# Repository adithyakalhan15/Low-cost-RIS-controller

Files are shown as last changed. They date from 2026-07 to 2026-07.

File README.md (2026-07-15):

## Intelligent RIS Controller and User-Tracking System

This repository contains the hardware-control, embedded firmware, edge-processing, and desktop-visualization components developed for a low-cost Reconfigurable Intelligent Surface system operating near 2.4 GHz.

The system controls a 6 × 4, 1-bit RIS panel through a 24-channel shift-register and MOSFET driver architecture. An ESP32-S3 collects target information from dual LD2450 mmWave radar sensors, while RSSI measurements provide additional wireless-positioning information. A Raspberry Pi processes the sensor data, selects RIS control patterns, and communicates with a Python-based desktop application for visualization, manual control, logging, and system monitoring.

The project demonstrates the integration of RF hardware, embedded systems, wireless sensing, edge processing, and software interfaces in a single experimental RIS platform.

### Main Features

* Independent control of 24 RIS cells
* ESP32-S3-based dual-radar data acquisition
* Radar and RSSI-assisted user tracking
* Raspberry Pi edge server and GPIO control
* Manual and automatic RIS pattern selection
* Python desktop dashboard for monitoring and visualization
* RF experimentation using Vivaldi antennas, an NI USRP N210, and spectrum-analysis equipment

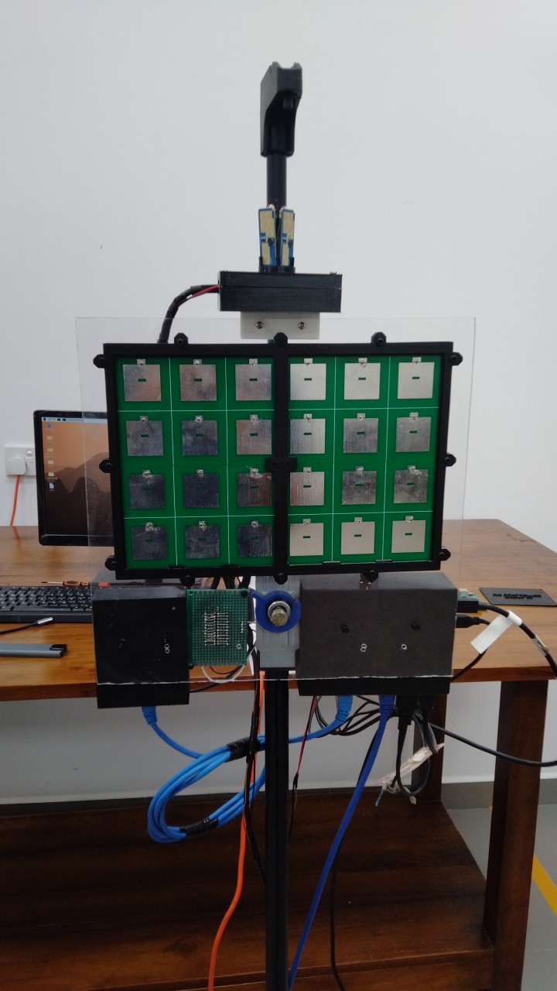
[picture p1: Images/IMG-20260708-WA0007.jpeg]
RIS setup with controller


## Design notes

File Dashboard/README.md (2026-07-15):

# RIS Master Modern Tabbed GUI — Performance Fixed

This version fixes UI freezing/messy rendering by throttling heavy Matplotlib redraws.

Key changes:
- Network packets are buffered; only the newest packet is rendered.
- Main UI refresh runs at 4 Hz.
- 2D plot redraws only when the Visual tab is active.
- 3D plot redraws slower, about 1 Hz, because 3D Matplotlib is expensive.
- Channel chart redraws only when the Channel tab is active.
- RIS panel remains 4 x 6 physical cells.
- Wire stream remains 32 bits: each 6-cell row + 2 dummy bits.

Run:

```bash
python -m venv .venv
```

Windows:

```powershell
.venv\Scripts\activate
pip install -r requirements.txt
python -m laptop_gui.main
```

Linux/Raspberry Pi OS/macOS:

```bash
source .venv/bin/activate
pip install -r requirements.txt
python -m laptop_gui.main
```

For Raspberry Pi connection:
- IP: your Pi Ethernet IP, for example 192.168.10.2
- Port: 5050
- Turn Simulation Mode OFF before connecting.

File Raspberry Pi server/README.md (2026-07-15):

# Raspberry Pi RIS Server — GPIO Scope Debug Final

This package is configured to **drive real Raspberry Pi GPIO pins by default** using a slow SPI-like bit-banged interface with the direct lgpio backend for a 74HC595 shift-register chain.

It also prints very clear hardware logs, including:

- whether GPIO output is enabled
- which physical pins and BCM GPIO numbers are used
- the exact 32-bit wire pattern
- the shifted bit order
- every DATA bit and CLOCK pulse during scope tests
- the final LATCH pulse confirmation
- direct lgpio backend, with no RPi.GPIO import

---

## Physical wiring

Wire by **physical pin number** on the Raspberry Pi header:

| Signal | Raspberry Pi physical pin | BCM GPIO used in Python | RJ45 pin | 74HC595 pin |
|---|---:|---:|---:|---:|
| DATA / MOSI-like | 19 | GPIO10 | 1 | 14 SER |
| CLOCK / SCLK-like | 23 | GPIO11 | 2 | 11 SRCLK |
| LATCH / RCLK-like | 24 | GPIO8 | 3 | 12 RCLK |
| GND | 6 or 9 | GND | 8 | 8 GND |

74HC595 fixed pins:

| 74HC595 pin | Connect to |
|---:|---|
| 16 VCC | 3.3 V recommended |
| 8 GND | Raspberry Pi GND |
| 13 OE | GND |
| 10 MR / SRCLR | VCC |

> Important: Raspberry Pi GPIO is 3.3 V logic. If your shift-register board is powered at 5 V, use a proper level shifter.

---

## What changed in this version

In `raspberry_pi_server/config.py`:

```python
ENABLE_HARDWARE_OUTPUT = True
GPIO_BIT_DELAY_S = 0.005
SCOPE_TEST_BIT_DELAY_S = 0.010
TELEMETRY_HZ = 1.0
HARDWARE_VERBOSE_PRINT = True
```

So the normal RIS server now writes to real GPIO pins by default. The scope test is even slower than the server output.

---

## Install on Raspberry Pi

Copy/extract this folder to the Raspberry Pi, then run:

```bash
cd ~/Desktop/raspberry_pi_ris_server_final_gpio_scope_debug
sudo apt update
sudo apt remove -y python3-rpi.gpio python3-rpi-lgpio
sudo apt install -y python3-venv python3-pip python3-lgpio
python3 -m venv .venv --system-site-packages
source .venv/bin/activate
python -m pip install --upgrade pip
pip install numpy onnxruntime pyserial
```

If serial permission fails:

```bash
sudo usermod -a -G dialout $USER
sudo reboot
```

Then activate again:

```bash
cd ~/Desktop/raspberry_pi_ris_server_final_gpio_scope_debug
source .venv/bin/activate
```

---

## GPIO library conflict fix

This version does **not** use `RPi.GPIO`. It imports `lgpio` directly.

Do not install both of these together for this package:

```bash
python3-rpi.gpio
python3-rpi-lgpio
```

Use only:

```bash
sudo apt install -y python3-lgpio
```

If GPIO claiming fails, try a different gpiochip:

```bash
ls /dev/gpiochip*
export RIS_GPIOCHIP=0
python3 scope_pin_test.py

# If needed, try:
export RIS_GPIOCHIP=4
python3 scope_pin_test.py
```

---

## Best oscilloscope test

Run this first before connecting the full RIS panel:

```bash
cd ~/Desktop/raspberry_pi_ris_server_final_gpio_scope_debug
source .venv/bin/activate
python3 scope_pin_test.py
```

Oscilloscope connections:

```text
Scope GND    -> Raspberry Pi physical pin 6 or 9
DATA probe   -> Raspberry Pi physical pin 19
CLOCK probe  -> Raspberry Pi physical pin 23
LATCH probe  -> Raspberry Pi physical pin 24
```

Expected:

```text
DATA  changes 0 V / 3.3 V according to the pattern
CLOCK gives 32 slow pulses per pattern
LATCH gives 1 pulse after each 32-bit transfer
```

The test prints every bit:

```text
[HW TX #1] bit 01/32 DATA=1 -> CLOCK pulse
[HW TX #1] bit 02/32 DATA=0 -> CLOCK pulse
...
[HW DONE #1] 32 clock pulses sent, latch pulsed, DATA left LOW.
```

To make it even slower, edit:

```bash
nano raspberry_pi_server/config.py
```

Change:

```python
SCOPE_TEST_BIT_DELAY_S = 0.020
```

---

## Shift-register hardware test

This also forces output ON and sends fixed patterns plus a walking-one test:

```bash
cd ~/Desktop/raspberry_pi_ris_server_final_gpio_scope_debug
source .venv/bin/activate
python3 test_shift_register.py
```

---

## Run final RIS server

```bash
cd ~/Desktop/raspberry_pi_ris_server_final_gpio_scope_debug
source .venv/bin/activate
python3 -m raspberry_pi_server.pi_server
```

Then connect the laptop GUI to the Raspberry Pi:

```text
IP: <your Raspberry Pi IP address>
Port: 5050
```

Useful command to find the Pi IP:

```bash
hostname -I
```

---

## If GPIO does not output

If you see this:

```text
[HW] RPi.GPIO import failed. Hardware output is disabled.
```

run:

```bash
sudo apt update
sudo apt install -y python3-rpi-lgpio python3-rpi.gpio
rm -rf .venv
python3 -m venv .venv --system-site-packages
source .venv/bin/activate
pip install numpy onnxruntime pyserial
python3 scope_pin_test.py
```

---

## Is this real SPI?

It is **SPI-like bit-banged GPIO**, not hardware `/dev/spidev` SPI.

That is intentional for debugging:

```text
DATA  = MOSI-like
CLOCK = SCLK-like
LATCH = CS/LOAD/RCLK-like
```

For the 74HC595 this is correct and easy to verify on the oscilloscope.

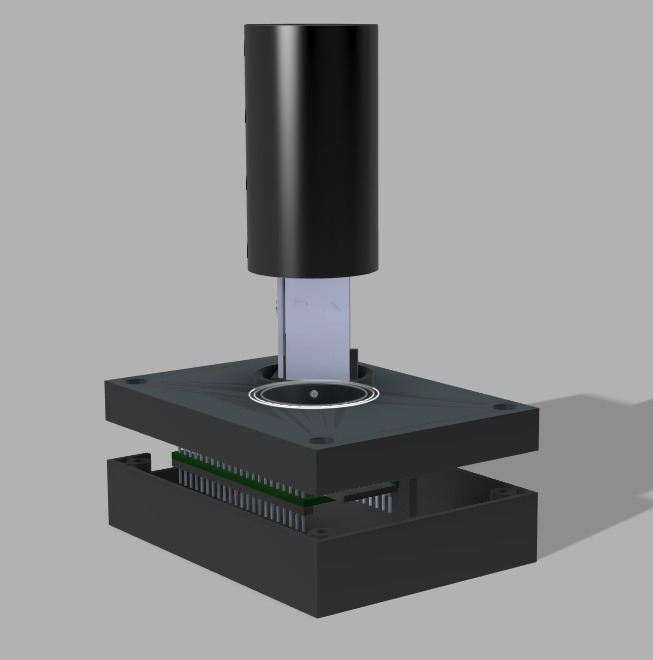
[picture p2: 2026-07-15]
Images/radar pod.jpeg

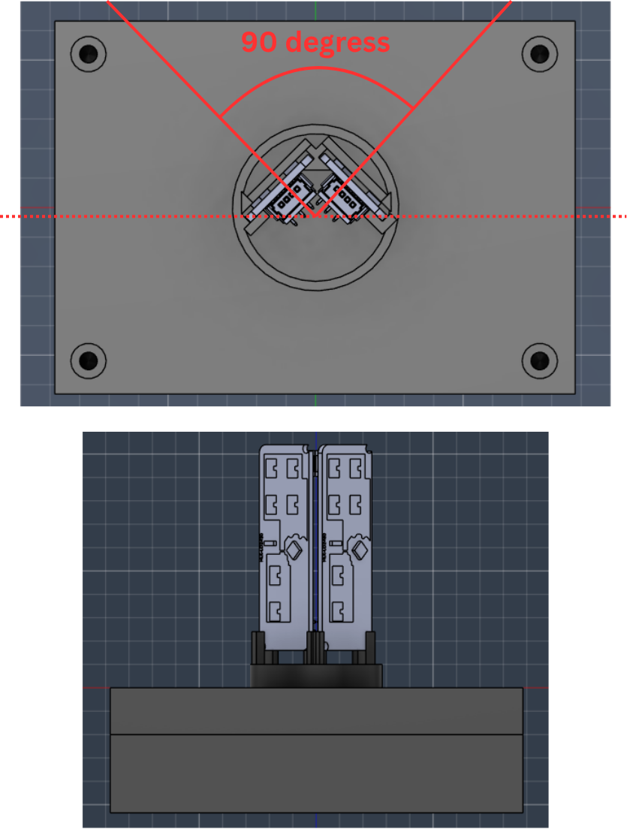
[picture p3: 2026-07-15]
Images/ON.png

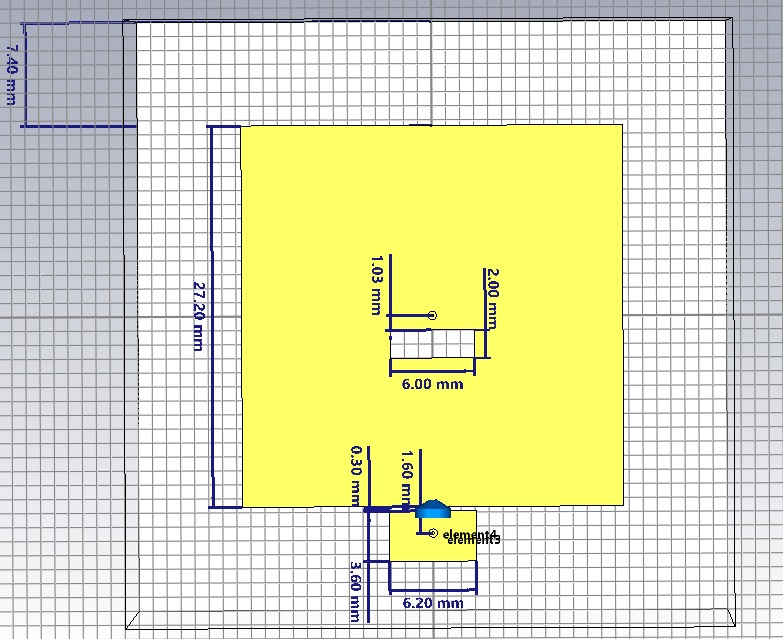
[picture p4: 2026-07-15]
Images/ris_unit_cell.jpeg

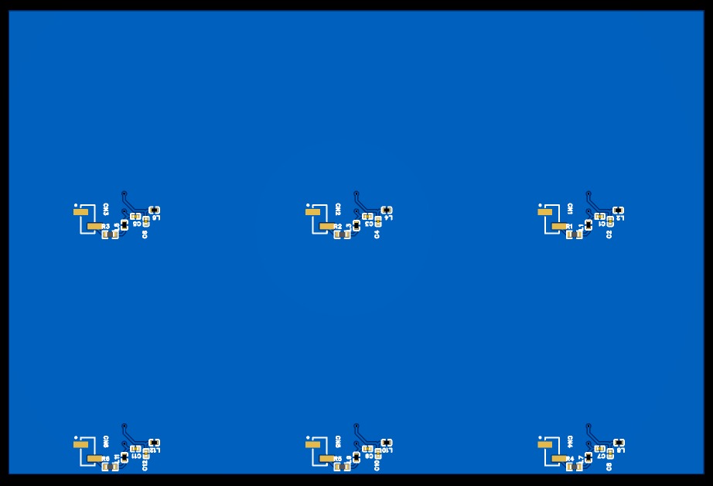
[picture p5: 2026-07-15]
Images/panel back.jpeg

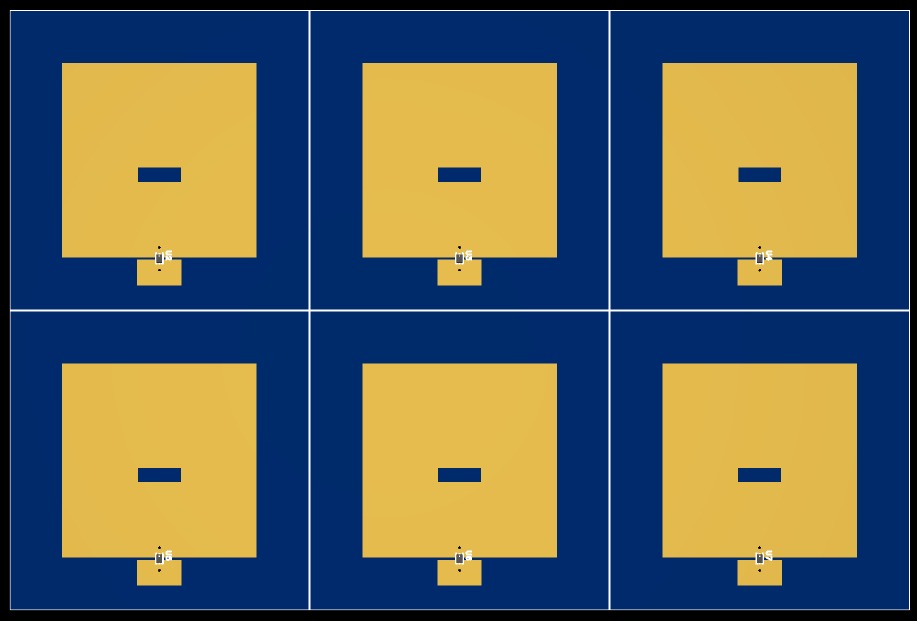
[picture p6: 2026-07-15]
Images/panel front.jpeg

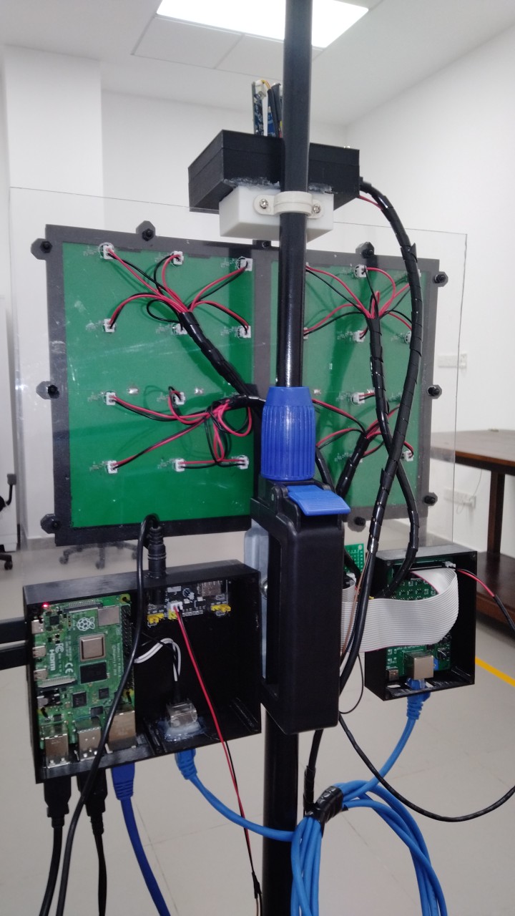
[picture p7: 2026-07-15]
Images/IMG-20260708-WA0011.jpeg

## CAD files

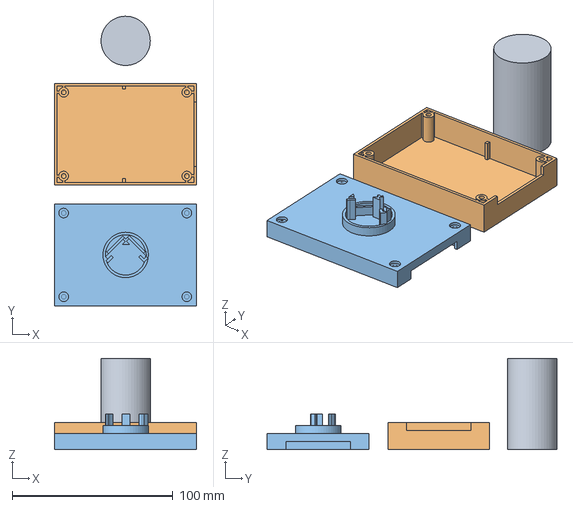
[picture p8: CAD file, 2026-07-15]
3D Files/Radar pod full.step
88.2 x 179.9 x 56.6 mm

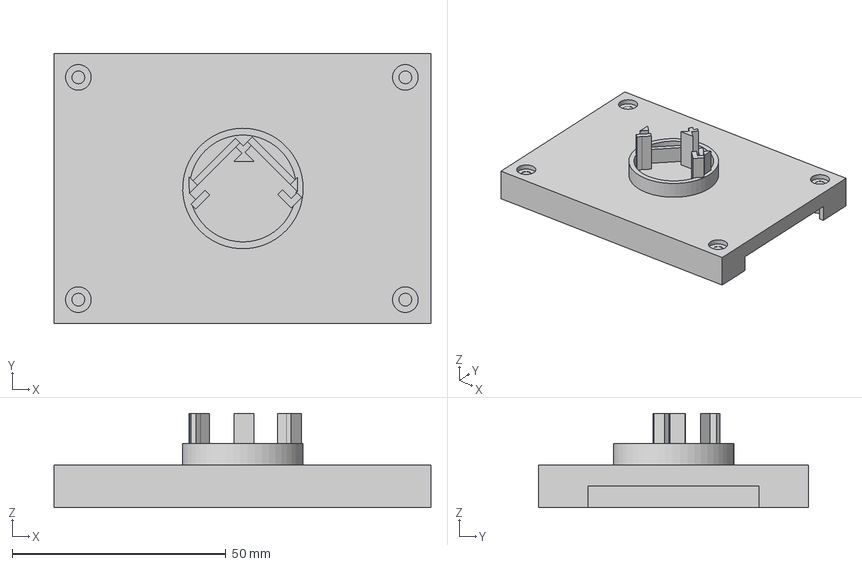
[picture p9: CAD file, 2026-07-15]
3D Files/Radar pod_top.step
88.2 x 63.2 x 22.0 mm

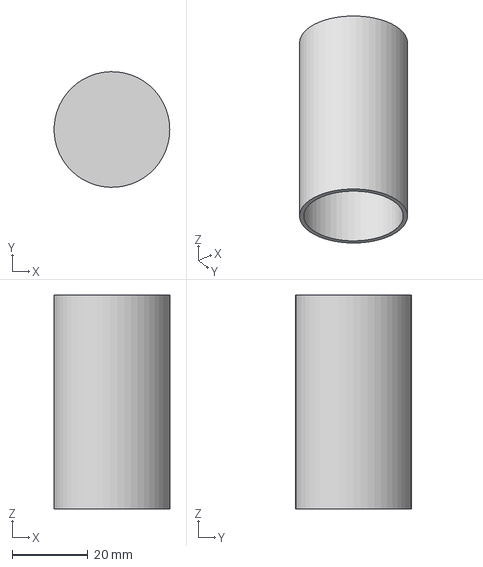
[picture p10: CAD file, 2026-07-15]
3D Files/Radar pod_radar cover.step
30.6 x 30.6 x 56.6 mm

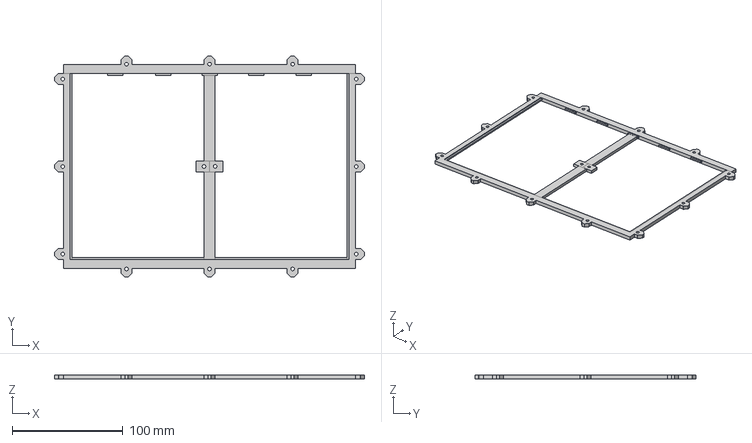
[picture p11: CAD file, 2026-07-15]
3D Files/RIS Frame part2.step
279.9 x 200.0 x 4.00 mm

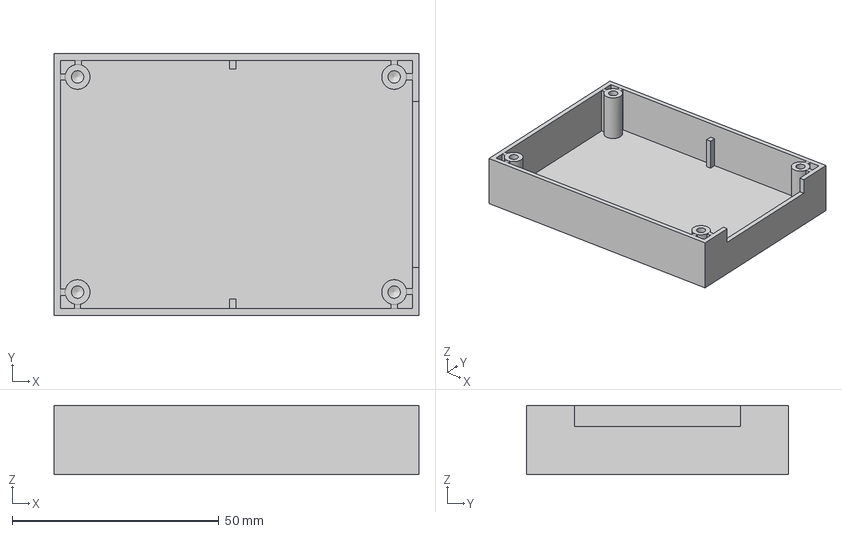
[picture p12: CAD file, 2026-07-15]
3D Files/Radar pod_bottom.step
88.2 x 63.2 x 16.8 mm

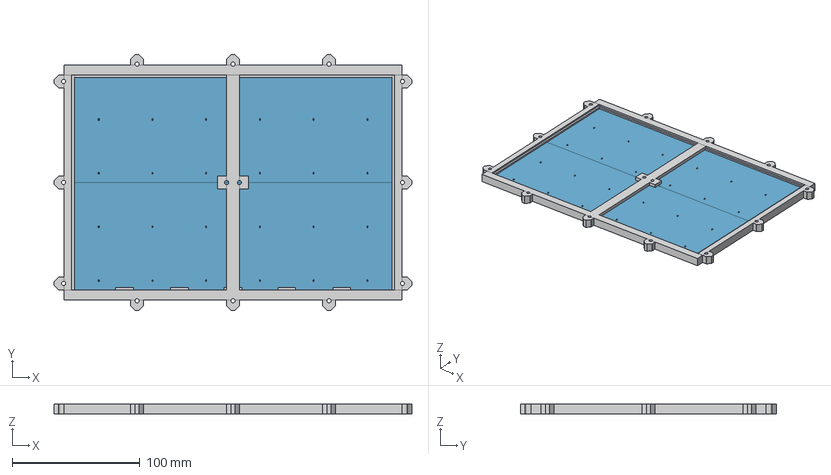
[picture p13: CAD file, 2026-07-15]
3D Files/RIS Frame.step
279.9 x 200.0 x 8.01 mm
Board~Lmov x 4
C0402~C0402_L1.0-W0.5-H0.5~Lmov x 48
R0603~R0603~Lmov x 24
SC-79_L1.2-W0.8-LS1.6-RD~SC-79_L1.2-W0.8-LS1.6-RD~Lmov x 24
IND-SMD_L1.0-W0.6~IND-SMD_L1.0-W0.6~Lmov x 48

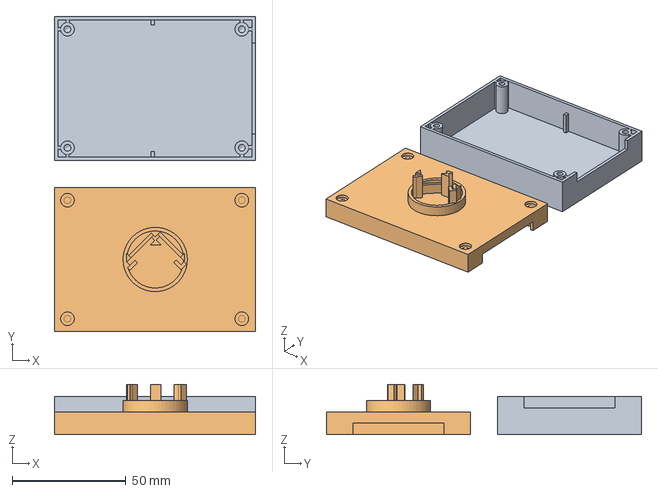
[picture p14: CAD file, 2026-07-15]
3D Files/Radar pod box part.step
88.2 x 138.2 x 22.0 mm

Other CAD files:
3D Files/Radar pod top cylinder.step
3D Files/RIS Frame part1.step

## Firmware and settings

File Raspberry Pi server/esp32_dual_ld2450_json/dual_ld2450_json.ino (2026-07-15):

#include <Arduino.h>
#include <LD2450.hpp>
#include <math.h>

using namespace esphome::ld245x;

// ================= UART PINS =================
// LD2450 TX -> ESP32 RX
// LD2450 RX -> ESP32 TX

#define RX_PIN_A 11
#define TX_PIN_A 10

#define RX_PIN_B 5
#define TX_PIN_B 4

// ================= SENSOR GEOMETRY =================
// Same physical mounting point.
// Surface normals separated by 90 degrees total.
// A looks +45 degrees, B looks -45 degrees.

const float ANGLE_SENSOR_A = 45.0;
const float ANGLE_SENSOR_B = -45.0;

const float OFFSET_X_A = 0.0;
const float OFFSET_Y_A = 0.0;

const float OFFSET_X_B = 0.0;
const float OFFSET_Y_B = 0.0;

// Fusion threshold in mm.
// If A and B transformed points are within this distance, treat as same target.
const float MERGE_DISTANCE_MM = 400.0;

// Remove stale fused targets after this time.
const uint32_t TARGET_TIMEOUT_MS = 1200;

// Ignore fake/zero targets closer than this distance.
const float MIN_VALID_DISTANCE_M = 0.15;

// Keep both false for Raspberry Pi serial input.
const bool DEBUG_UART = false;
const bool PRINT_MEAS_JSON = false;

HardwareSerial ld2450Serial_A(1);
HardwareSerial ld2450Serial_B(2);

enum SensorID {
  SENSOR_A,
  SENSOR_B
};

struct RadarPacket {
  SensorID sensor;
  int id;
  int16_t x;
  int16_t y;
  int16_t speed;
  uint16_t resolution;
};

struct RadarTaskParams {
  HardwareSerial* serial;
  SensorID sensor;
  const char* name;
};

struct FusedTarget {
  bool active;
  int id;
  float x;
  float y;
  float speed;
  uint32_t lastSeen;
};

QueueHandle_t radarQueue;
FusedTarget fusedTargets[6];

RadarTaskParams radarAParams = { .serial = &ld2450Serial_A, .sensor = SENSOR_A, .name = "A" };
RadarTaskParams radarBParams = { .serial = &ld2450Serial_B, .sensor = SENSOR_B, .name = "B" };

float toRadians(float degrees) { return degrees * (PI / 180.0); }
float distanceM(float x_m, float y_m) { return sqrt((x_m * x_m) + (y_m * y_m)); }

bool isValidTargetMeters(float x_m, float y_m) {
  return distanceM(x_m, y_m) >= MIN_VALID_DISTANCE_M;
}

bool isValidTargetMm(float x_mm, float y_mm) {
  return isValidTargetMeters(x_mm / 1000.0, y_mm / 1000.0);
}

void localToGlobal(SensorID sensor, float localX, float localY, float &globalX, float &globalY) {
  float angle = 0.0;
  float offsetX = 0.0;
  float offsetY = 0.0;

  if (sensor == SENSOR_A) {
    angle = toRadians(ANGLE_SENSOR_A);
    offsetX = OFFSET_X_A;
    offsetY = OFFSET_Y_A;
  } else {
    angle = toRadians(ANGLE_SENSOR_B);
    offsetX = OFFSET_X_B;
    offsetY = OFFSET_Y_B;
  }

  float c = cos(angle);
  float s = sin(angle);

  globalX = (localX * c) - (localY * s) + offsetX;
  globalY = (localX * s) + (localY * c) + offsetY;
}

void cleanupStaleTargets() {
  uint32_t now = millis();
  for (int i = 0; i < 6; i++) {
    if (fusedTargets[i].active && (now - fusedTargets[i].lastSeen > TARGET_TIMEOUT_MS)) {
      fusedTargets[i].active = false;
    }
  }
}

int countActiveTargets() {
  int count = 0;
  for (int i = 0; i < 6; i++) {
    if (!fusedTargets[i].active) continue;
    if (isValidTargetMm(fusedTargets[i].x, fusedTargets[i].y)) count++;
  }
  return count;
}

int updateFusedTarget(float globalX, float globalY, float speed) {
  uint32_t now = millis();

  if (!isValidTargetMm(globalX, globalY)) {
    return -1;
  }

  int bestIndex = -1;
  float bestDistance = 999999.0;

  for (int i = 0; i < 6; i++) {
    if (!fusedTargets[i].active) continue;

    float dx = fusedTargets[i].x - globalX;
    float dy = fusedTargets[i].y - globalY;
    float distance = sqrt((dx * dx) + (dy * dy));

    if (distance < MERGE_DISTANCE_MM && distance < bestDistance) {
      bestDistance = distance;
      bestIndex = i;
    }
  }

  if (bestIndex >= 0) {
    fusedTargets[bestIndex].x = (0.65 * fusedTargets[bestIndex].x) + (0.35 * globalX);
    fusedTargets[bestIndex].y = (0.65 * fusedTargets[bestIndex].y) + (0.35 * globalY);
    fusedTargets[bestIndex].speed = (0.65 * fusedTargets[bestIndex].speed) + (0.35 * speed);
    fusedTargets[bestIndex].lastSeen = now;
    return bestIndex;
  }

  for (int i = 0; i < 6; i++) {
    if (!fusedTargets[i].active) {
      fusedTargets[i].active = true;
      fusedTargets[i].id = i;
      fusedTargets[i].x = globalX;
      fusedTargets[i].y = globalY;
      fusedTargets[i].speed = speed;
      fusedTargets[i].lastSeen = now;
      return i;
    }
  }

  return -1;
}

void printFusedTargetJson(int fusedID) {
  if (fusedID < 0) return;
  if (!fusedTargets[fusedID].active) return;

  float x_m = fusedTargets[fusedID].x / 1000.0;
  float y_m = fusedTargets[fusedID].y / 1000.0;
  float distance_m = distanceM(x_m, y_m);

  if (distance_m < MIN_VALID_DISTANCE_M) return;

  float angle_deg = atan2(y_m, x_m) * 180.0 / PI;
  float speed_value = fusedTargets[fusedID].speed;
  int activeTargets = countActiveTargets();

  Serial.printf(
    "{\"x\":%.3f,\"y\":%.3f,\"angle\":%.2f,\"distance\":%.3f,\"speed\":%.2f,\"targets\":%d}\n",
    x_m, y_m, angle_deg, distance_m, speed_value, activeTargets
  );
}

void printMeasurementJson(const char* sensorName, int rawID, float localX, float localY, float globalX, float globalY, float speed) {
  float local_x_m = localX / 1000.0;
  float local_y_m = localY / 1000.0;
  float global_x_m = globalX / 1000.0;
  float global_y_m = globalY / 1000.0;

  if (!isValidTargetMeters(global_x_m, global_y_m)) return;

  Serial.printf(
    "{\"type\":\"meas\",\"sensor\":\"%s\",\"raw_id\":%d,\"local_x\":%.3f,\"local_y\":%.3f,\"global_x\":%.3f,\"global_y\":%.3f,\"speed\":%.2f}\n",
    sensorName, rawID, local_x_m, local_y_m, global_x_m, global_y_m, speed
  );
}

void vRadarTask(void *pvParameters) {
  RadarTaskParams* params = (RadarTaskParams*)pvParameters;

  HardwareSerial* radarSerial = params->serial;
  SensorID sensorID = params->sensor;
  const char* sensorName = params->name;

  if (DEBUG_UART) Serial.printf("Radar task started: %s\n", sensorName);

  LD2450 detector;
  radarSerial->setTimeout(1000);
  detector.begin(*radarSerial);

  delay(500);
  detector.beginConfigurationSession();
  detector.setMultiTargetTracking();
  detector.endConfigurationSession();

  RadarPacket packet;
  packet.sensor = sensorID;
  uint32_t lastDebug = millis();

  for (;;) {
    if (detector.update()) {
      int validTargets = detector.getNrValidTargets();

      while (validTargets > 0) {
        validTargets--;
        auto target = detector.getTarget(validTargets);

        packet.id = target.id;
        packet.x = target.x;
        packet.y = target.y;
        packet.speed = target.v;
        packet.resolution = target.res;

        xQueueSend(radarQueue, &packet, pdMS_TO_TICKS(5));
      }
    }

    if (DEBUG_UART && millis() - lastDebug > 2000) {
      Serial.printf("DEBUG | Sensor: %s | UART available: %d\n", sensorName, radarSerial->available());
      lastDebug = millis();
    }

    vTaskDelay(pdMS_TO_TICKS(10));
  }
}

void vBrainTask(void *pvParameters) {
  RadarPacket receivedTarget;

  if (DEBUG_UART) Serial.println("SYSTEM | Dual LD2450 tracking started");

  for (;;) {
    if (xQueueReceive(radarQueue, &receivedTarget, portMAX_DELAY) == pdTRUE) {
      float localX = receivedTarget.x;
      float localY = receivedTarget.y;
      float globalX = 0.0;
      float globalY = 0.0;

      localToGlobal(receivedTarget.sensor, localX, localY, globalX, globalY);

      if (!isValidTargetMm(globalX, globalY)) {
        cleanupStaleTargets();
        continue;
      }

      int fusedID = updateFusedTarget(globalX, globalY, receivedTarget.speed);
      const char* sensorName = receivedTarget.sensor == SENSOR_A ? "A" : "B";

      if (PRINT_MEAS_JSON) {
        printMeasurementJson(sensorName, receivedTarget.id, localX, localY, globalX, globalY, receivedTarget.speed);
      }

      cleanupStaleTargets();

      if (fusedID >= 0 && fusedTargets[fusedID].active) {
        printFusedTargetJson(fusedID);
      }
    }
  }
}

void setup() {
  Serial.begin(115200);
  delay(2000);

  if (DEBUG_UART) {
    Serial.println();
    Serial.println("SYSTEM | Starting dual LD2450 test");
  }

  ld2450Serial_A.begin(256000, SERIAL_8N1, RX_PIN_A, TX_PIN_A);
  ld2450Serial_B.begin(256000, SERIAL_8N1, RX_PIN_B, TX_PIN_B);

  radarQueue = xQueueCreate(30, sizeof(RadarPacket));

  if (radarQueue == NULL) {
    if (DEBUG_UART) Serial.println("ERROR | Failed to create radarQueue");
    return;
  }

  xTaskCreatePinnedToCore(vRadarTask, "Radar_A_Task", 8192, &radarAParams, 2, NULL, 1);
  xTaskCreatePinnedToCore(vRadarTask, "Radar_B_Task", 8192, &radarBParams, 2, NULL, 1);
  xTaskCreatePinnedToCore(vBrainTask, "Brain_Task", 8192, NULL, 1, NULL, 1);
}

void loop() {
  vTaskDelay(pdMS_TO_TICKS(1000));
}

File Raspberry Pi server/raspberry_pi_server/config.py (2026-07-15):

from pathlib import Path

# ================= TCP SERVER =================
HOST = "0.0.0.0"
PORT = 5050

# Slow enough that GPIO writes do not spam while debugging with oscilloscope.
# You can increase later after hardware is confirmed.
TELEMETRY_HZ = 4.0

# ================= RIS PANEL =================
# Physical panel: 4 rows x 6 columns = 24 real controllable cells
RIS_ROWS = 4
RIS_COLS = 6
RIS_CELLS = RIS_ROWS * RIS_COLS

# Driver/wire stream: each row sends 8 bits = 6 real bits + 2 dummy bits.
# Current mapping: Row = C0 C1 C2 C3 C4 C5 D D
# IMPORTANT: GUI sends 24 physical bits plus 32 wire_bits. The server now writes
# GUI-provided wire_bits exactly for manual mode, and only maps physical bits when
# no 32-bit wire stream is supplied.
DUMMY_BITS_PER_ROW = "00"


# ================= GPIO TEST INVERSION =================
# True = server receives normal GUI bits, but writes the INVERSE to GPIO.
# This is useful when your driver/shift-register/transistor stage is active-low
# or when you want to verify inverted bit patterns on the oscilloscope.
# Example GUI cell_bits 1010... -> GPIO wire_bits 0101... including dummy bits.
INVERT_GUI_PATTERN_TO_GPIO = True

# ================= ML MODEL =================
BASE_DIR = Path(__file__).resolve().parents[1]
MODEL_PATH = BASE_DIR / "models" / "GTN_24.onnx"

# Physics / ML geometry
FREQ_HZ = 2.4e9
C_LIGHT = 3e8
TX_AZ_DEG = 45.0
TX_EL_DEG = 0.0
TX_DIST_M = 10.0
RIS_CENTER = (0.0, 0.0, 2.0)

# ================= RADAR SERIAL =================
# ESP32 -> Raspberry Pi through USB serial.
# Keep None for auto-detect. Set "/dev/ttyUSB0" or "/dev/ttyACM0" if needed.
RADAR_SERIAL_PORT = None
RADAR_BAUDRATE = 115200

# Set False to use real ESP32 serial radar.
# If serial fails, it automatically falls back to simulation.
USE_SIMULATED_RADAR = False

# ================= CHANNEL =================
# For now channel values are based on ML prediction + demo noise.
USE_SIMULATED_CHANNEL = True

# ================= HARDWARE OUTPUT =================
# True = bit-bang DATA/CLOCK/LATCH GPIO to 74HC595 through RJ45.
# False = print 32-bit wire stream only.
# Final demo default is now TRUE because you asked for real GPIO output.
ENABLE_HARDWARE_OUTPUT = True

# Avoid hammering hardware with same repeated pattern in normal server mode.
# Set False only when you intentionally want repeated identical waveforms.
ONLY_WRITE_HARDWARE_ON_CHANGE = True

# Print clear GPIO/write details for every hardware frame.
HARDWARE_VERBOSE_PRINT = False

# True = if GPIO cannot be imported/claimed, commands return ERROR instead of silently simulating.
# This prevents the GUI/server from pretending that GPIO was written when it was not.
REQUIRE_REAL_GPIO_ACTIVE = True

# Raspberry Pi GPIO numbering used by Python code: BCM numbering.
# Wire using PHYSICAL pin numbers on the Raspberry Pi header:
#   Physical pin 19 -> DATA  / MOSI  -> RJ45 pin 1 -> 74HC595 SER pin 14
#   Physical pin 23 -> CLOCK / SCLK  -> RJ45 pin 2 -> 74HC595 SRCLK pin 11
#   Physical pin 24 -> LATCH / CE0   -> RJ45 pin 3 -> 74HC595 RCLK pin 12
#   Physical pin 6  -> GND           -> RJ45 pin 8 -> 74HC595 GND pin 8

# lgpio GPIO chip number. Usually 0 on Raspberry Pi OS.
# If claiming pins fails, try: export RIS_GPIOCHIP=4 then rerun scope_pin_test.py
GPIO_CHIP = 0

# BCM numbers for those same physical pins:
GPIO_DATA_PIN = 10    # physical pin 19
GPIO_CLOCK_PIN = 11   # physical pin 23
GPIO_LATCH_PIN = 8    # physical pin 24

# Bit-bang delay between GPIO transitions.
# 0.005 s = very easy to see on oscilloscope.
# Approx frame time is around 0.65 s for 32 bits.
# For even slower viewing, use 0.010.
# For final fast operation later, use 0.00005 to 0.0001.
GPIO_BIT_DELAY_S = 0.0001

# Dedicated slower delay for scope_pin_test.py.
# This overrides GPIO_BIT_DELAY_S only inside the scope test.
SCOPE_TEST_BIT_DELAY_S = 0.010

# Time between full 32-bit patterns in scope_pin_test.py.
SCOPE_TEST_PATTERN_PAUSE_S = 1.0

# Backward-compatible alias used by older driver code.
SHIFT_BIT_DELAY_S = GPIO_BIT_DELAY_S

# True = first character in wire_bits is shifted first.
# If your physical output order appears reversed, change this to False.
SHIFT_MSB_FIRST = True

# ================= RSSI + NETWORK PERSON TRACKING =================
# This is an add-on. It does not replace the existing LD2450 RadarReceiver.
# ESP32 anchor nodes send UDP JSON to Raspberry Pi:
#   {"id":"A","mac":"AA:BB:CC:DD:EE:FF","rssi":-55,"csi_amp":[]}
ENABLE_RSSI_PERSON_TRACKING = True
RSSI_UDP_BIND_IP = "0.0.0.0"
RSSI_UDP_PORT = 4210
RSSI_PRINT_PACKETS = False

# Simple room/anchor geometry for RSSI weighted-centroid estimation.
ROOM_WIDTH_M = 2.0
ROOM_HEIGHT_M = 2.0
RIS_REF_X_M = 1.0
RIS_REF_Y_M = 0.0
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

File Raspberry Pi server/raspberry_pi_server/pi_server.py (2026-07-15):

import socket
import threading
import time
import traceback
from typing import Optional

from shared.protocol import encode_json_line, decode_json_lines
from . import config
from .ris_controller import RISController
from .radar_receiver import RadarReceiver
from .channel_monitor import ChannelMonitor
from .ml_pattern_engine import MLPatternEngine
from .rssi_person_tracker import RssiPersonTracker


class RISPiServer:
    def __init__(self):
        self.host = config.HOST
        self.port = config.PORT
        self.running = False

        self.ris = RISController()
        self.radar = RadarReceiver(
            port=config.RADAR_SERIAL_PORT,
            baudrate=config.RADAR_BAUDRATE,
            simulation=config.USE_SIMULATED_RADAR,
        )
        self.channel = ChannelMonitor()
        self.ml = MLPatternEngine(config.MODEL_PATH)
        self.person_tracker = RssiPersonTracker()

        self.client_sock: Optional[socket.socket] = None
        self.client_lock = threading.Lock()
        self.latest_radar = None
        self.latest_prediction = None

    def start(self):
        self.running = True
        self.radar.start()
        self.person_tracker.start()

        server = socket.socket(socket.AF_INET, socket.SOCK_STREAM)
        server.setsockopt(socket.SOL_SOCKET, socket.SO_REUSEADDR, 1)
        server.bind((self.host, self.port))
        server.listen(1)

        print("=" * 72)
        print("RIS Raspberry Pi Controller Server")
        print(f"Listening on {self.host}:{self.port}")
        print(f"Telemetry rate: {config.TELEMETRY_HZ} Hz")
        print(f"Model: {config.MODEL_PATH}")
        print(f"Radar serial: port={config.RADAR_SERIAL_PORT or 'AUTO'} baud={config.RADAR_BAUDRATE}")
        print("Connect the Laptop GUI to this Raspberry Pi IP and port 5050.")
        print("=" * 72)

        try:
            while self.running:
                print("[SERVER] Waiting for laptop GUI client...")
                client, addr = server.accept()
                print(f"[SERVER] Client connected: {addr}")

                with self.client_lock:
                    if self.client_sock:
                        try:
                            self.client_sock.close()
                        except Exception:
                            pass
                    self.client_sock = client

                rx_thread = threading.Thread(target=self._receive_loop, args=(client,), daemon=True)
                tx_thread = threading.Thread(target=self._telemetry_loop, args=(client,), daemon=True)
                rx_thread.start()
                tx_thread.start()

                rx_thread.join()
                print("[SERVER] Client disconnected.")

        except KeyboardInterrupt:
            print("\n[SERVER] Stopped by user.")
        finally:
            self.running = False
            self.radar.stop()
            self.person_tracker.stop()
            try:
                server.close()
            except Exception:
                pass

    def _receive_loop(self, client: socket.socket):
        buffer = ""
        while self.running:
            try:
                data = client.recv(4096)
                if not data:
                    break

                buffer += data.decode("utf-8", errors="replace")
                packets, buffer = decode_json_lines(buffer)

                for packet in packets:
                    self._handle_command(packet)

            except Exception as e:
                print(f"[RX] Error: {e}")
                traceback.print_exc()
                break

        with self.client_lock:
            if self.client_sock is client:
                self.client_sock = None
        try:
            client.close()
        except Exception:
            pass

    def _handle_command(self, packet):
        print(f"[CMD] {packet}")

        if packet.get("type") != "command":
            return

        cmd = str(packet.get("cmd", "")).upper()

        try:
            if cmd == "SET_MODE":
                self.ris.set_mode(packet.get("mode", "AUTO"))

            elif cmd in ("APPLY_PATTERN", "GPIO_WRITE", "DIRECT_WIRE_BITS", "SET_BITS"):
                print("[CMD APPLY] raw cell_bits=", packet.get("cell_bits"))
                print("[CMD APPLY] raw wire_bits=", packet.get("wire_bits") or packet.get("bits"))
                ok = self.ris.apply_manual_pattern(
                    cell_bits=packet.get("cell_bits"),
                    wire_bits=packet.get("wire_bits") or packet.get("bits"),
                    pattern_id=packet.get("pattern_id", 0),
                )
                self._send_packet({
                    "type": "ack" if ok else "error",
                    "cmd": cmd,
                    "message": "GPIO write completed. Check CLOCK/LATCH on oscilloscope now." if ok else "GPIO NOT ACTIVE: command received, but no electrical output was written.",
                    "wire_bits": self.ris.state.wire_bits,
                    "cell_bits": self.ris.state.cell_bits,
                    "gpio_ready": bool(self.ris.hw.ready),
                    "gpio_enabled": bool(self.ris.hw.enabled),
                    "gpio": self.ris.hw.status_dict(),
                })
                # Send immediate status back so GUI does not wait for next telemetry tick.
                self._send_packet(self._build_telemetry_packet())

            elif cmd == "RESET_RIS":
                self.ris.reset()
                self._send_packet(self._build_telemetry_packet())

            elif cmd == "EMERGENCY_OFF":
                self.ris.emergency_off()
                self._send_packet(self._build_telemetry_packet())

            elif cmd == "GET_STATUS":
                self._send_packet(self._build_telemetry_packet())

            else:
                print(f"[CMD] Unknown command: {cmd}")

        except Exception as e:
            print(f"[CMD] Failed: {e}")
            self._send_packet({
                "type": "error",
                "message": str(e),
                "bad_command": packet,
            })

    def _telemetry_loop(self, client: socket.socket):
        dt = 1.0 / max(config.TELEMETRY_HZ, 0.1)

        while self.running:
            with self.client_lock:
                if self.client_sock is not client:
                    break

            try:
                packet = self._build_telemetry_packet()
                client.sendall(encode_json_line(packet))
                time.sleep(dt)

            except Exception as e:
                print(f"[TX] Error: {e}")
                break

    def _build_telemetry_packet(self):
        radar = self.radar.get_position()
        self.latest_radar = radar
        self.person_tracker.update_radar(radar)
        person = self.person_tracker.get_selection()
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

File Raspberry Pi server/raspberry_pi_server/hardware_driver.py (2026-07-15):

import os
import time
from . import config

try:
    import lgpio
    LGPIO_AVAILABLE = True
    LGPIO_IMPORT_ERROR = None
except Exception as exc:
    lgpio = None
    LGPIO_AVAILABLE = False
    LGPIO_IMPORT_ERROR = exc


class RISHardwareDriver:
    """
    Raspberry Pi 3-wire bit-bang driver for cascaded 74HC595 shift registers.

    IMPORTANT:
    This version uses the real lgpio library directly.
    It does NOT import RPi.GPIO, so it avoids the python3-rpi.gpio / python3-rpi-lgpio conflict.

        DATA  -> physical pin 19 -> BCM GPIO10 -> 74HC595 SER
        CLOCK -> physical pin 23 -> BCM GPIO11 -> 74HC595 SRCLK
        LATCH -> physical pin 24 -> BCM GPIO8  -> 74HC595 RCLK
        GND   -> physical pin 6/9 -> GND

    Input wire_bits must be a 32-character string.
    For this 4x6 RIS panel:
        24 real cell bits -> 4 rows x (6 real bits + 2 dummy bits) = 32 bits
    """

    def __init__(
        self,
        enabled=None,
        data_pin=None,
        clock_pin=None,
        latch_pin=None,
        bit_delay_s=None,
        only_write_on_change=None,
        verbose=None,
        gpiochip=None,
    ):
        self.enabled = bool(config.ENABLE_HARDWARE_OUTPUT if enabled is None else enabled)
        self.data_pin = int(config.GPIO_DATA_PIN if data_pin is None else data_pin)
        self.clock_pin = int(config.GPIO_CLOCK_PIN if clock_pin is None else clock_pin)
        self.latch_pin = int(config.GPIO_LATCH_PIN if latch_pin is None else latch_pin)
        self.bit_delay_s = float(config.GPIO_BIT_DELAY_S if bit_delay_s is None else bit_delay_s)
        self.only_write_on_change = bool(
            config.ONLY_WRITE_HARDWARE_ON_CHANGE if only_write_on_change is None else only_write_on_change
        )
        self.verbose = bool(config.HARDWARE_VERBOSE_PRINT if verbose is None else verbose)

        env_chip = os.environ.get("RIS_GPIOCHIP")
        default_chip = getattr(config, "GPIO_CHIP", 0)
        self.requested_gpiochip = int(env_chip if env_chip is not None else (default_chip if gpiochip is None else gpiochip))
        self.chip = None
        self.active_gpiochip = None
        self.last_wire_bits = None
        self.ready = False
        self.frame_counter = 0
        self.start()

    def start(self):
        print("[HW] Driver starting...")
        print(f"[HW] GPIO backend=lgpio direct, no RPi.GPIO import")
        print(f"[HW] ENABLE_HARDWARE_OUTPUT={self.enabled}")
        print(f"[HW] ONLY_WRITE_HARDWARE_ON_CHANGE={self.only_write_on_change}")
        print(f"[HW] SHIFT_MSB_FIRST={config.SHIFT_MSB_FIRST}")
        print(f"[HW] GPIO_BIT_DELAY_S={self.bit_delay_s}")
        print(f"[HW] Requested GPIO chip={self.requested_gpiochip}  override with: export RIS_GPIOCHIP=0")
        print(f"[HW] REQUIRE_REAL_GPIO_ACTIVE={getattr(config, 'REQUIRE_REAL_GPIO_ACTIVE', True)}")
        self._print_mapping()

        if not self.enabled:
            print("[HW] Hardware output disabled. Print-only simulation mode.")
            return

        if not LGPIO_AVAILABLE:
            print("[HW] lgpio import failed. Hardware output is disabled.")
            print(f"[HW] Import error: {LGPIO_IMPORT_ERROR}")
            print("[HW] Install only lgpio, not RPi.GPIO:")
            print("[HW]   sudo apt update")
            print("[HW]   sudo apt remove -y python3-rpi.gpio python3-rpi-lgpio")
            print("[HW]   sudo apt install -y python3-lgpio")
            print("[HW]   python3 -m venv .venv --system-site-packages")
            self.enabled = False
            self.ready = False
            return

        pins = [self.data_pin, self.clock_pin, self.latch_pin]
        chips_to_try = [self.requested_gpiochip] + [c for c in range(0, 6) if c != self.requested_gpiochip]
        last_error = None

        for chip_number in chips_to_try:
            try:
                chip = lgpio.gpiochip_open(chip_number)
                for pin in pins:
                    lgpio.gpio_claim_output(chip, pin, 0)
                self.chip = chip
                self.active_gpiochip = chip_number
                self.ready = True
                break
            except Exception as exc:
                last_error = exc
                try:
                    if 'chip' in locals() and chip is not None:
                        lgpio.gpiochip_close(chip)
                except Exception:
                    pass

        if not self.ready:
            print("[HW] Could not open/claim GPIO pins using lgpio.")
            print(f"[HW] Last error: {last_error}")
            print("[HW] Try these checks:")
            print("[HW]   ls /dev/gpiochip*")
            print("[HW]   sudo usermod -aG gpio $USER && sudo reboot")
            print("[HW]   export RIS_GPIOCHIP=0   # or 1/2/3/4 depending on your Pi")
            print("[HW]   python3 scope_pin_test.py")
            self.enabled = False
            return

        print(f"[HW] Hardware output ENABLED using lgpio on /dev/gpiochip{self.active_gpiochip}.")
        print("[HW] Initial pin states: DATA=LOW, CLOCK=LOW, LATCH=LOW")

    def _print_mapping(self):
        print("[HW] Wiring by Raspberry Pi physical pin:")
        print("[HW]   DATA  physical pin 19 / BCM GPIO10 -> RJ45 pin 1 -> 74HC595 SER pin 14")
        print("[HW]   CLOCK physical pin 23 / BCM GPIO11 -> RJ45 pin 2 -> 74HC595 SRCLK pin 11")
        print("[HW]   LATCH physical pin 24 / BCM GPIO8  -> RJ45 pin 3 -> 74HC595 RCLK pin 12")
        print("[HW]   GND   physical pin 6 or 9          -> RJ45 pin 8 -> 74HC595 GND pin 8")

    def status_dict(self):
        return {
            "enabled": bool(self.enabled),
            "ready": bool(self.ready),
            "backend": "lgpio-direct",
            "lgpio_available": bool(LGPIO_AVAILABLE),
            "active_gpiochip": self.active_gpiochip,
            "requested_gpiochip": self.requested_gpiochip,
            "data_pin_bcm": self.data_pin,
            "clock_pin_bcm": self.clock_pin,
            "latch_pin_bcm": self.latch_pin,
            "last_wire_bits": self.last_wire_bits,
        }

    def stop(self):
        try:
            self.set_all_low(cleanup=False)
        except Exception:
            pass

        if LGPIO_AVAILABLE and self.ready and self.chip is not None:
            try:
                for pin in [self.data_pin, self.clock_pin, self.latch_pin]:
                    try:
                        lgpio.gpio_free(self.chip, pin)
                    except Exception:
                        pass
                lgpio.gpiochip_close(self.chip)
            except Exception:
                pass

        self.chip = None
        self.ready = False
        print("[HW] Hardware driver stopped.")
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
